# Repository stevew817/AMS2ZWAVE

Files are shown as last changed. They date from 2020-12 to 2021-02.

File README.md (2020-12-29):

# AMS2ZWAVE
Converter for Norwegian EMI HAN interface to Z-Wave

# Disclaimer
This is a hobby project, and as such will be supported if and when I have the time.

The project is assumed to work for my situation, but it might not work for you. Use at your own risk.

Furthermore, since I am not a member of the Z-Wave SDO, there is no manufacturer/product ID officially assigned to this device.
I don't have the funds required to certify this device, nor the wish to do so myself. This means the IDs in use in this firmware can
be assigned to another manufacturer at any given point in time, breaking the operation of this device in hubs that utilize
device databases (which would be all of them given device configuration parameters are not always discoverable on the network).

Or, more likely, there will be other hobby projects that choose to use the same ID as the default in here.
In that case, you'll have to recompile one of them yourself with a different ID to avoid collisions if they're to be used against the same hub.

If you are affiliated with an SDO-registered company and wish to take this design to market, feel free to do so. I'd appreciate a heads-up, though.

# License
Hardware design is licensed CC-BY: https://creativecommons.org/licenses/by/4.0/

The Z-Wave application code is adapted from a sample application [supplied by Silicon Labs on Github](https://github.com/SiliconLabs/z_wave_applications/tree/1341a074053843d77aac94dc1ba609a796c5856e/z_wave_gesture_sensor_wall_controller_application). The sample applications in that repository are licensed under the Zlib license, and so are my modifications.

Other files that do not originate from the sample application (notably my own HAN parser), are also licensed under the Zlib license.

# Hardware
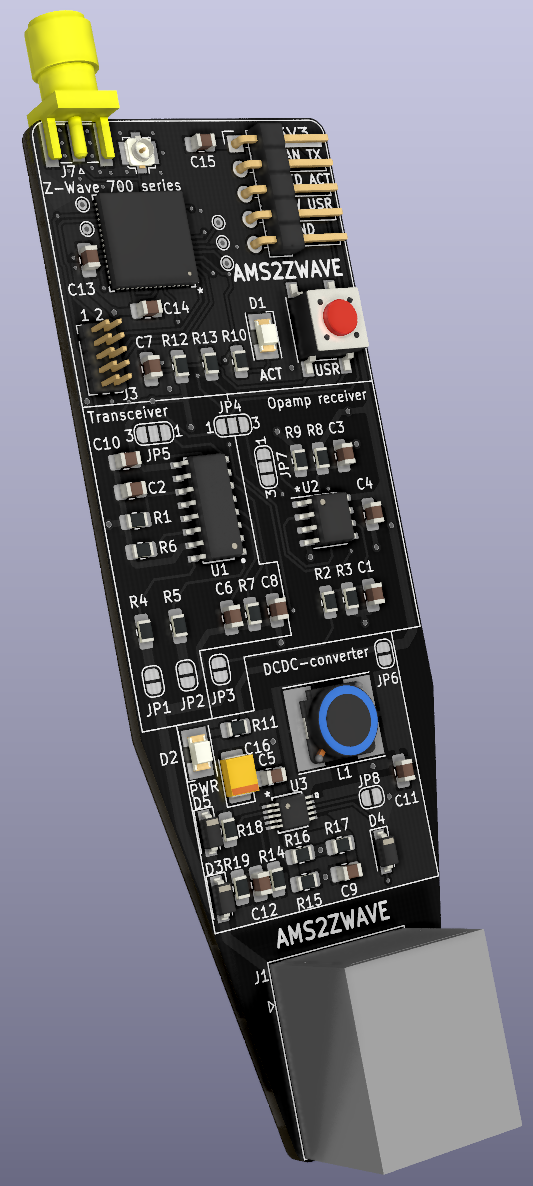
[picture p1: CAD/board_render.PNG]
Prototype hardware design Prototype PCB render


[PDF Schematic](CAD/AMS2ZWAVE.pdf)

Schematic and board layout are done in KiCAD, and source files can be found in the `CAD` folder.
[Production files for my prototype order](CAD/Gerber/ams2zwave_v1.zip) are also supplied.

## Choice of Z-Wave circuit
I consider this design to be hand-solderable, with the exception of the ZGM130S System-in-Package. Until a Z-Wave 700 series module is
designed and brought to market with a more hobbyist-friendly form factor, you'll have to use a stencil and solder paste to reflow that part.

For prototyping purposes, this design also contains a header to allow it to be wired up to a development kit, instead of having to solder down the ZGM130S.
In that case, the design will act as a bus level translator, power supply and user interface.
For a Silicon Labs WSTK (BRD4001) with ZGM130S plug-in card (BRD4202), wire the `J4` header as follows to the WSTK's `EXP` header:

| Signal | J4  | EXP | ZGM130S |
| --- | --- | --- | --- |
| VMCU | 1 | 2 | (A)VDD(IO) |
| GND | 5 | 1 | GND |
| HAN_TX | 2 | 6 | PC7 / USART1_RX |
| LED1 | 3 | 13  | PF3 |
| BTN1 | 4 | 9 | PF7 |

## Choice of bus level translation
Norwegian HAN is M-Bus with a twist: all meters observed to date supply 24V 'at rest' (space).
[Mark signal should be 12V under the space voltage](https://m-bus.com/documentation-wired/04-physical-layer), so with that in mind, I have prototyped
two different circuits for converting the HAN signal level to 3V3 TTL.

### Dedicated IC
The 'transceiver' circuit uses an m-bus transceiver, but foregoes using its internal LDO for powering the Z-Wave circuit in favor of a separate DCDC. Avoiding
using the LDO allows the circuit to be much more efficient and not trip any overcurrent protections in the HAN bus master implementation.

Using a transceiver is a more expensive solution, but should also be more reliable in case another meter appears that decides to use actual M-bus voltages (+36/+24)
instead of the currently observed de-facto +24/+12 signal.

Pin-compatible devices are TI's TSS521/TSS721 or ON Semi's NCN5150.

### Opamp
A cheaper alternative (but needs to be validated that it works) is a comparator circuit driven off of the 3V3 supply, looking at the HAN signal through a simple
voltage divider. The resistor values specified would divide the input signal by 12 (i.e. 2V space, 1V mark) and put the reference voltage at 1.75V.

### Setting the jumpers

| Jumper | Function | Default setting (uncut/unsoldered) |
| --- | --- | --- |
| JP6 | Connect DCDC output to 3V3 line | connected |
| JP1 | Connect HAN port input 1 to transceiver circuit | unconnected |
| JP2 | Connect HAN port input 2 to transceiver circuit | unconnected |
| JP3 | Connect HAN port input to opamp circuit | unconnected |
| JP5 | Select between normal (1) or inverted (3) transceiver output | normal |
| JP7 | Select between normal (1) or inverted (3) opamp output | normal |
| JP4 | Select source of `HAN_TX` signal between transceiver (1)(output of `JP5`) and opamp (3)(output of `JP7`) circuit  | transceiver / JP5 |

Of note: this circuit won't give you any signal by default. You need to choose to either use the transceiver-based circuit for level translation by soldering
jumpers `JP1` and `JP2`, or select the opamp circuit by soldering `JP3` and moving `JP4` from its default 1-2 position to 2-3.

## DCDC converter and power consumption
The DCDC converter is based around a MAX17531 step-down converter, and designed according to [the datasheet's figure 7](https://datasheets.maximintegrated.com/en/ds/MAX17531.pdf),
*High-Efficiency 3.3V, 50mA Regulator*. Under normal operation, the device will draw about 10 - 14 mA from the 3V3 line, meaning it will be operating at
about 85% efficiency.

This results in a top power draw of about 50mW from the HAN interface (plus the transceiver circuit's static current draw), which is well within spec
for all of the currently deployed meters in Norway. The lowest-power ones (Kamstrup meters) are spec'ed to supply 144mW / 6mA continuously.

## Z-Wave circuit
The circuit was designed based off of the Silicon Labs reference design boards (BRD4202A and BRD8901A, available in Simplicity Studio). Due to the nature
of the SiP, the core design is *extremely* lightweight: 2 decouple caps and an antenna connector. The distance between the SiP and the connector is so short
vs. the wavelength, that impedance control is unlikely to make a difference. The SiP's output is already matched to 50 ohm, so as long as the connected antenna
is also matched to 50 ohms, the design should be good to go.

Debug connector is a 0.05" pitch, 2x5 pinheader. The pinout matches the 'mini simplicity' connector described in Silicon Labs' [application note AN958](https://www.silabs.com/documents/public/application-notes/an958-mcu-stk-wstk-guide.pdf).
This makes it so that the circuit can be debugged by a Silicon Labs development kit [with the appropriate adapter](https://www.silabs.com/development-tools/mcu/32-bit/simplicity-debug-adapter), or
really any other SWD debug probe with the 10-pin ARM connector. Using the Silicon Labs kit gives the possibility to trace energy usage and have a debug serial port
from inside the IDE, though.

The button and activity LED are routed to the same pins as in the Z-Wave SDK's reference applications.

The HAN signal is routed to the Z-Wave SDK's reference application 'USART 1' RX pin. It's a 2400 baud 8-N-1 or 8-E-1 signal.

# Software
The software is an adaptation of the ['Gesture Wall Controller' Z-Wave sample app](https://github.com/SiliconLabs/z_wave_applications/tree/master/z_wave_gesture_sensor_wall_controller_application).

Changes include:
* Stripped out 'central scene' CC and dependencies
* Stripped out associations that are not the lifeline group
* Implemented 'meter' CC
* Changed device type to 'generic meter'
* Bogus manufacturer/product ID
* Implemented a parser for the HAN signal:
    * Uses list identifiers to parse the incoming information. This means a firmware update would be required to support any new meters appearing on the Norwegian market. Shouldn't be much of an issue, since the firmware does support OTA updates.
    * Lives in a [separate repository](http://github.com/stevew817/ams-han-parser)
* Implemented configuration CC to support changing the reporting frequency
    * The Configuration CC should be easily usable by other projects as well, as it was written generically.

Todo:
* Add separate endpoints for getting phase-specific values on three-phase meters (root endpoint currently reports L1 values for voltage and current).
* Add support for reporting both active and reactive power / energy
* Add support for reporting export direction

To build the firmware:
1. Download and install Simplicity Studio
2. Install the Z-Wave SDK inside Simplicity Studio (project was created with Z-Wave SDK 7.15.x)
3. Import this repository (including submodules) as a project into Simplicity Studio
4. Build

To fully flash a blank device:
1. Flash the bootloader (`bin/AMS2ZWAVE-btl-combined.s37`) to the device
    * This is the same bootloader as the SDK-provided one, except it allows firmware downgrading and sidegrading.
2. Flash the sign & encrypt keys to the device, following [step 7 in this guide](https://www.silabs.com/community/wireless/z-wave/knowledge-base.entry.html/2019/04/09/z-wave_700_ota_ofe-i00M)
    * This repository is set up to generate .gbl files using the 'default' keys in the SDK, so you don't have to generate your own
    * For the default keys, flash these files using commander with the --tokenfile argument:
        * `${StudioSdkPath}/protocol/z-wave/BootLoader/sample-keys/sample_encrypt.key`
        * `${StudioSdkPath}/protocol/z-wave/BootLoader/sample-keys/sample_sign.key-tokens.txt`
3. Flash the application like you normally would
4. Verify debug output to check the device is working and responsive

## Z-Wave operation
Device only has a single association group, which is the lifeline group. It will report meter updates unsolicited to the node registered to the lifeline group.
Frequent updates report power draw, whilst the accumulated meter reading is only reported once an hour (see the HAN standard from NEK). This is a limitation of the HAN standard.

The node could theoretically average the reported power draw in-between getting the accumulated meter reading reports, but since some meters only report power for the last second every 10s, that opens up a possibility of averaging higher than actual, and thus 'overestimating' the meter reading within the hour. That would mean the reported accumulated value could potentially go backwards once an hour, and it's not a given that various systems will be able to cope with that.

The controller can ask ('poll') for other values (like voltage and current), but there is currently no support for reporting these automatically.
I consider the use case for grabbing these values fairly narrow, since line voltage shouldn't deviate from 230V too much, and you can calculate backwards from
the reported power draw to get a 'good-enough' estimation of current.

## Development
The root of this repository is importable as a Simplicity Studio project, and targets the Z-Wave SDK version 7.15.4. Both Simplicity Studio and the Z-Wave SDK
are free downloads after registering with Silicon Labs.

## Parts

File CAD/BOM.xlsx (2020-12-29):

 |  |  |  |  |  | prototype build |  | transceiver build |  | opamp build
category | Description | symbol | footprint | part number | unit price | count | total price | count | total price | count | total price | proto stock | Mouser bom
mechanical | SubGHz antenna |  |  | ANTX150P116B08683 | 1.5 | 1 | 1.5 | 1 | 1.5 | 1 | 1.5 |  | X
 | PCB |  |  |  | 1 | 1 | 1 | 1 | 1 | 1 | 1
 | RJ45 connector | J1 | amphenol 54602-x08 | 54602-908LF | 0.5 | 1 | 0.5 | 1 | 0.5 | 1 | 0.5 |  | X
DCDC | DCDC converter | U3 | 10-MSOP | MAX17531AUB | 1.5 | 1 | 1.5 | 1 | 1.5 | 1 | 1.5 |  | X
 | Low-Vf schottky diode, 30V | D3 | SOD-123 | BAT54GWX | 0.1 | 1 | 0.1 | 1 | 0.1 | 1 | 0.1 |  | X
 | Input capacitor, 30V 1uF | C5 | 0805 | CL21B105KBFNNNE | 0.05 | 1 | 0.05 | 1 | 0.05 | 1 | 0.05 |  | X
 | Output capacitor, 5V 10uF low ESR | C11 | 0805 | CL21A106KQFNNNG | 0.07 | 1 | 0.07 | 1 | 0.07 | 1 | 0.07 | X | X
 | reference stabilisation cap, 5V 220nF | C9 | 0805 | CL21B224KBFNNNG | 0.05 | 1 | 0.05 | 1 | 0.05 | 1 | 0.05 |  | X
 | Precision resistor 49.9k | R15 | 0805 | RC0805FR-0749K9L | 0.02 | 1 | 0.02 | 1 | 0.02 | 1 | 0.02 |  | X
 | Precision resistor 158k | R16 | 0805 | RC0805FR-07158KL | 0.02 | 1 | 0.02 | 1 | 0.02 | 1 | 0.02 |  | X
 | Precision resistor 140k | R14 | 0805 | RC0805FR-07140KL | 0.02 | 1 | 0.02 | 1 | 0.02 | 1 | 0.02 |  | X
 | Precision resistor 22.1 Ohm | R17 | 0805 | RC0805FR-0722R1L | 0.02 | 1 | 0.02 | 1 | 0.02 | 1 | 0.02 |  | X
 | Low-impedance inductor 220uH | L1 | 8040 | TYS8040221M-10 | 0.3 | 1 | 0.3 | 1 | 0.3 | 1 | 0.3 |  | X
 | Low-Vf schottky diode, 5V | D4 | SOD-123 | BAT54GWX | 0.1 | 1 | 0.1 | 1 | 0.1 | 1 | 0.1 |  | X
Transceiver | mbus transceiver | U1 | SOIC-16 | NCN5150DR2G | 2 | 1 | 2 | 1 | 2 |  |  |  | X
 | Bus termination resistor, 220 Ohm | R4, R5 | 0805 | RC0805FR-0722RL | 0.02 | 2 | 0.04 | 2 | 0.04 |  |  |  | X
 | Bus current set resistor, 470Ohm | R6 | 0805 | RC0805FR-07470RL | 0.02 | 1 | 0.02 | 1 | 0.02 |  |  |  | X
 | Slave current resistor, 82k | R7 | 0805 | RC0805FR-0782KL | 0.02 | 1 | 0.02 | 1 | 0.02 |  |  |  | X
 | transceiver decouple resistor, 100k | R1 | 0805 | RC0805FR-07100KL | 0.02 | 1 | 0.02 | 1 | 0.02 |  |  | X | X
 | Transceiver decouple cap, 100n | C2 | 0805 | CL21B104KCFNNNE | 0.02 | 1 | 0.02 | 1 | 0.02 |  |  | X | X
 | IO decouple cap, 100n | C10 | 0805 | CL21B104KCFNNNE | 0.02 | 1 | 0.02 | 1 | 0.02 |  |  | X | X
 | Bus level storage cap, 100n | C8 | 0805 | CL21B104KCFNNNE | 0.02 | 1 | 0.02 | 1 | 0.02 |  |  | X | X
 | Supply backup cap, 1u | C6 | 0805 | CL21B105KOFNNNG | 0.05 | 1 | 0.05 | 1 | 0.05 |  |  | X | X
Opamp | opamp | U2 | SOIC-8 | LM358LVIDR | 0.3 | 1 | 0.3 |  |  | 1 | 0.3 |  | X
 | decouple cap 100n | C4 | 0805 | CL21B104KCFNNNE | 0.02 | 1 | 0.02 |  |  | 1 | 0.02 | X | X
 | Voltage divider resistor 33k (11/12) | R2 | 0805 | RC0805FR-0733KL | 0.02 | 1 | 0.02 |  |  | 1 | 0.02 |  | X
 | Voltage divider resistor 3k (1/12) | R3 | 0805 | RC0805FR-073KL | 0.02 | 1 | 0.02 |  |  | 1 | 0.02 |  | X
 | Voltage divider resistor 24k (47%) | R8 | 0805 | RC0805FR-0724KL | 0.02 | 1 | 0.02 |  |  | 1 | 0.02 |  | X
 | Voltage divider resistor 27k (53%) | R9 | 0805 | RC0805FR-0727KL | 0.02 | 1 | 0.02 |  |  | 1 | 0.02 |  | X
 | Divider stabilising caps 100n | C1, C3 | 0805 | CL21B104KCFNNNE | 0.02 | 2 | 0.04 |  |  | 2 | 0.04 | X | X
Z-Wave | ZGM130S | U4 | LGA64 | ZGM130S037HGN2R | 6 | 1 | 6 | 1 | 6 | 1 | 6 |  | X
 | ZGM decoupling caps 10uF | C13, C14 | 0805 | CL21A106KQFNNNG | 0.07 | 2 | 0.14 | 2 | 0.14 | 2 | 0.14 | X | X
 | U.fl / ipex connector | J2 | U.fl | Molex 73412-0110 | 0.6 | 1 | 0.6 | 1 | 0.6 | 1 | 0.6 |  | X
 | Mini simplicity connector | J3 | .05" 2x5 male header | 20021111-00010T1LF | 0.5 | 1 | 0.5 | 0 | 0 | 0 | 0 |  | X
 | Prototype connector | J4 | right-angle .1" pinhd | 10129379-905001BLF | 0.08 | 1 | 0.08 | 0 | 0 | 0 | 0 | X | X
 | Input decouple prototype 100n | C15 | 0805 | CL21B104KCFNNNE | 0.02 | 1 | 0.02 | 0 | 0 | 0 | 0 | X | X
 | LED current limiting resistors 3k | R10, R11 | 0805 | RC0805FR-073KL | 0.02 | 2 | 0.04 | 2 | 0.04 | 2 | 0.04 |  | X
 | Power-on indicator LED, red | D1 | PLCC2 | CLM3C-RKW-CUBVAAA3 | 0.15 | 1 | 0.15 | 1 | 0.15 | 1 | 0.15 |  | X
 | Zwave activity LED, amber | D2 | PLCC2 | CLM3C-AKW-CUAVB253 | 0.15 | 1 | 0.15 | 1 | 0.15 | 1 | 0.15 |  | X
 | Zwave user button | SW1 | 6x6mm | PTS645SK50SMTR92LFS | 0.14 | 1 | 0.14 | 1 | 0.14 | 1 | 0.14 |  | X
 | User button pullup 1M | R12 | 0805 | RC0805FR-071ML | 0.04 | 1 | 0.04 | 1 | 0.04 | 1 | 0.04 |  | X
 | User button snubber cap 1n | C7 | 0805 | CL21B102KBANNNC | 0.04 | 1 | 0.04 | 1 | 0.04 | 1 | 0.04 |  | X
 | User button snubber r, 100 Ohm | R13 | 0805 | RC0805FR-07100RL | 0.02 | 1 | 0.02 | 1 | 0.02 | 1 | 0.02 | X | X
 |  |  |  |  | USD |  | 15.82 |  | 14.78 |  | 13.01

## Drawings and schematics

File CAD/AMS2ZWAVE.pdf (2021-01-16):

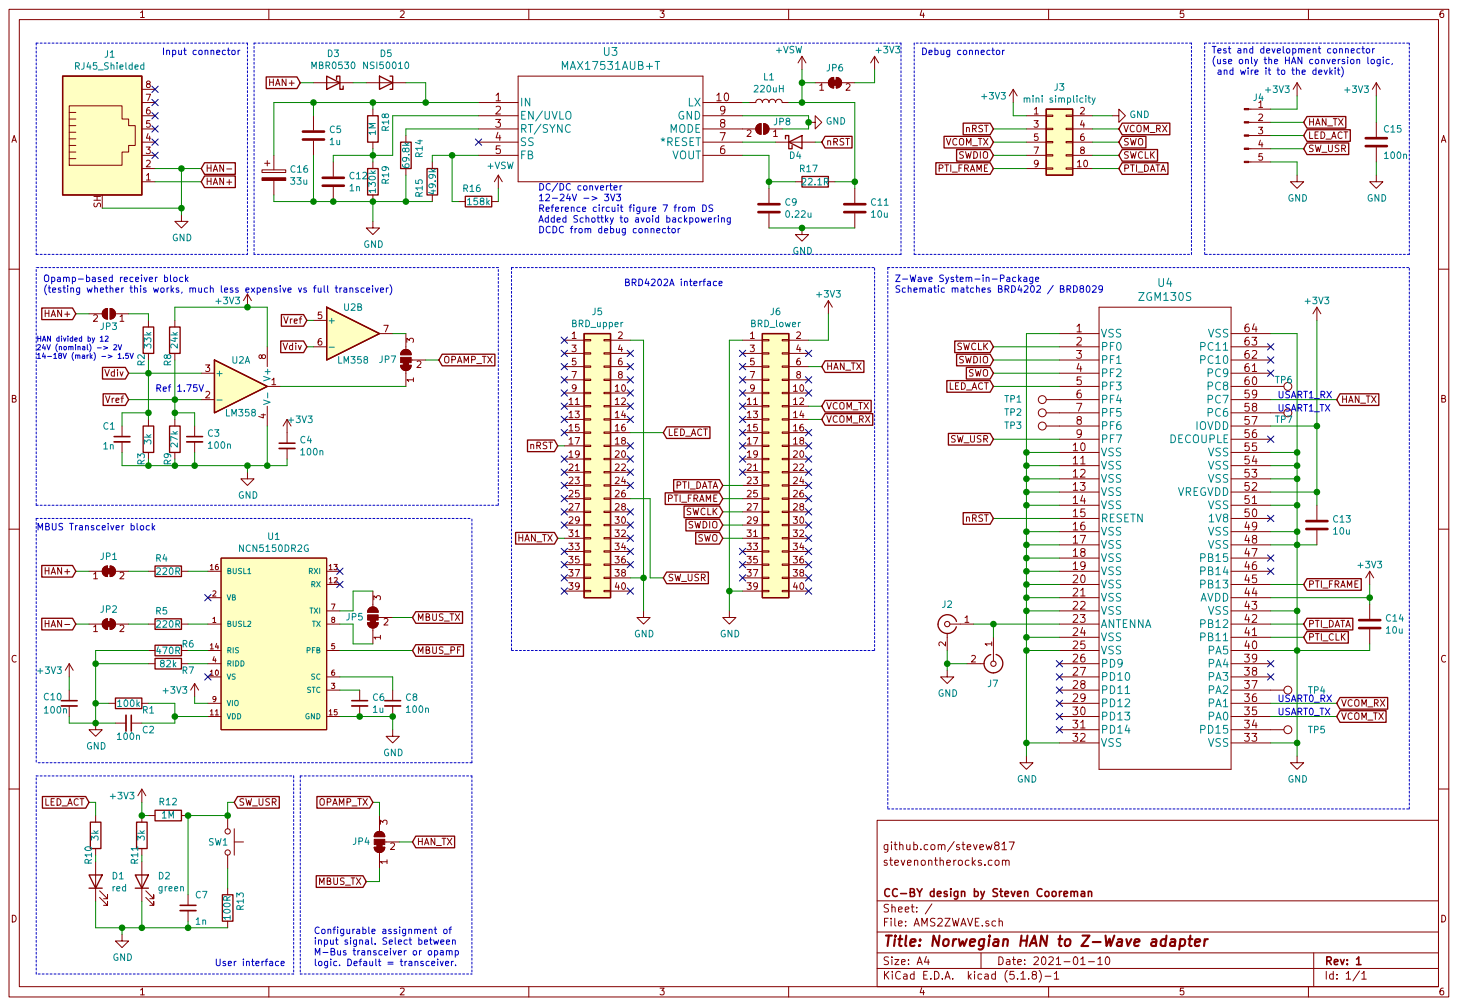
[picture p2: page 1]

(use only the HAN conversion logic,

Added Schottky to avoid backpowering
DCDC from debug connector
100n GND

14-18V (mark) -> 1.5V Opamp-based receiver block

Id: 1/1 Title: Norwegian HAN to Z-Wave adapter File: AMS2ZWAVE.sch Sheet: / CC-BY design by Steven Cooreman

input signal. Select between

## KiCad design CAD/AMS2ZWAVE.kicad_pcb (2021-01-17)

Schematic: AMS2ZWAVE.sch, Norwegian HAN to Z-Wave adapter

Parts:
C1, C7, C12: 1n; C_0805_2012Metric_Pad1.18x1.45mm_HandSolder
C2, C3, C4, C8, C10, C15: 100n; C_0805_2012Metric_Pad1.18x1.45mm_HandSolder
C5, C6: 1u; C_0805_2012Metric_Pad1.18x1.45mm_HandSolder
C9: 0.22u; C_0805_2012Metric_Pad1.18x1.45mm_HandSolder
C11, C13, C14: 10u; C_0805_2012Metric_Pad1.18x1.45mm_HandSolder
C16: 33u; CP_EIA-2012-12_Kemet-R_Pad1.30x1.05mm_HandSolder
D1: red; LED_PLCC-2
D2: green; LED_PLCC-2
D3, D4: MBR0530; D_SOD-123
D5: NSI50010; D_SOD-123
J1: RJ45_Shielded; RJ45_Amphenol_54602-x08_Horizontal
J2: Conn_Coaxial; U.FL_Molex_MCRF_73412-0110_Vertical
J3: mini simplicity; PinHeader_2x05_P1.27mm_Vertical
J4: Conn_01x05_Male; PinHeader_1x05_P2.54mm_Horizontal
J5: BRD_upper; PinHeader_2x20_P1.27mm_Vertical_SMD
J6: BRD_lower; PinHeader_2x20_P1.27mm_Vertical_SMD
J7: Conn_Coaxial; SMA_Samtec_SMA-J-P-X-ST-EM1_EdgeMount
JP1, JP2: SolderJumper_2_Open; SolderJumper-2_P1.3mm_Bridged_RoundedPad1.0x1.5mm
JP3, JP8: SolderJumper_2_Open; SolderJumper-2_P1.3mm_Open_RoundedPad1.0x1.5mm
JP4, JP5, JP7: SolderJumper_3_Bridged12; SolderJumper-3_P1.3mm_Bridged12_RoundedPad1.0x1.5mm_NumberL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
JP6: SolderJumper_2_Bridged; SolderJumper-2_P1.3mm_Bridged2Bar_RoundedPad1.0x1.5mm
L1: 220uH; L_Taiyo-Yuden_NR-80xx_HandSoldering
R1: 100k; R_0805_2012Metric_Pad1.20x1.40mm_HandSolder
R2: 33k; R_0805_2012Metric_Pad1.20x1.40mm_HandSolder
R3, R10, R11: 3k; R_0805_2012Metric_Pad1.20x1.40mm_HandSolder
R4, R5: 220R; R_0805_2012Metric_Pad1.20x1.40mm_HandSolder
R6: 470R; R_0805_2012Metric_Pad1.20x1.40mm_HandSolder
R7: 82k; R_0805_2012Metric_Pad1.20x1.40mm_HandSolder
R8: 24k; R_0805_2012Metric_Pad1.20x1.40mm_HandSolder
R9: 27k; R_0805_2012Metric_Pad1.20x1.40mm_HandSolder
R12, R18: 1M; R_0805_2012Metric_Pad1.20x1.40mm_HandSolder
R13: 100R; R_0805_2012Metric_Pad1.20x1.40mm_HandSolder
R14: 69.8k; R_0805_2012Metric_Pad1.20x1.40mm_HandSolder
R15: 49.9k; R_0805_2012Metric_Pad1.20x1.40mm_HandSolder
R16: 158k; R_0805_2012Metric_Pad1.20x1.40mm_HandSolder
R17: 22.1R; R_0805_2012Metric_Pad1.20x1.40mm_HandSolder
R19: 130k; R_0805_2012Metric_Pad1.20x1.40mm_HandSolder
SW1: SW_Push; SW_SPST_PTS645
TP1, TP2, TP3, TP4, TP5, TP6, TP7: TestPoint; TestPoint_THTPad_D1.0mm_Drill0.5mm
U1: NCN5150DR2G; On_Semiconductor-NCN5150DR2G
U2: LM358; SOIC-8_3.9x4.9mm_P1.27mm
U3: MAX17531AUB+T; MAX17531AUB&plus_T
U4: ZGM130S

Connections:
+3V3: C4.1, C10.1, C13.1, C14.1, C15.1, J3.1, J4.1, J6.2, JP6.2 (B), R8.2, R11.2, R12.1, U1.9 (VIO), U2.8 (V+), U4.44 (AVDD), U4.52 (VREGVDD), U4.57 (IOVDD)
+VSW: C11.1, JP6.1 (A), L1.2, R16.1, R17.1
HAN+: D3.2 (A), J1.1, JP1.1 (A), JP3.2 (B)
HAN-: C1.2, C2.2, C3.2, C4.2, C5.2, C6.2, C7.2, C8.2, C9.2, C10.2, C11.2, C12.2, C13.2, C14.2, C15.2, C16.2, D1.1 (K), D2.1 (K), J1.2, J1.SH, J2.2 (Ext), J3.2, J4.5, J5.2, J5.38, J6.1, J6.39, J7.2 (Ext), JP2.1 (A), JP8.1 (A), R1.2, R3.1, R6.2, R7.2, R9.1, R13.1, R14.2, R15.2, R19.1, U1.15 (GND), U2.4 (V-), U3.9 (GND), U4.1 (VSS), U4.10 (VSS), U4.11 (VSS), U4.12 (VSS), U4.13 (VSS), U4.14 (VSS), U4.16 (VSS), U4.17 (VSS), U4.18 (VSS), U4.19 (VSS), U4.20 (VSS), U4.21 (VSS), U4.22 (VSS), U4.24 (VSS), U4.25 (VSS), U4.32 (VSS), U4.33 (VSS), U4.40 (PA5), U4.43 (VSS), U4.48 (VSS), U4.49 (VSS), U4.51 (VSS), U4.53 (VSS), U4.54 (VSS), U4.55 (VSS), U4.64 (VSS)
HAN_TX: J4.2, J5.31, J6.6, JP4.2 (C), U4.59 (PC7)
LED_ACT: J4.3, J5.16, R10.2, U4.5 (PF3)
MBUS_PF: U1.5 (PFB)
MBUS_TX: JP4.1 (A), JP5.2 (C)
unnamed: C2.1, R1.1, U1.11 (VDD)
unnamed: C6.1, U1.3 (STC)
unnamed: C8.1, U1.6 (SC)
unnamed: C9.1, R17.2, U3.6 (VOUT)
unnamed: C12.1, R18.1, R19.2, U3.2 (EN/UVLO)
unnamed: C5.1, C16.1, D5.1, R18.2, U3.1 (IN)
unnamed: D1.2 (A), R10.1
unnamed: D2.2 (A), R11.1
unnamed: D3.1 (K), D5.2
unnamed: D4.1 (K), U3.7 (*RESET)
unnamed: J2.1 (In), J7.1 (In), U4.23 (ANTENNA)
unnamed: JP1.2 (B), R4.2
unnamed: JP2.2 (B), R5.2
unnamed: JP3.1 (A), R2.2
unnamed: JP5.1 (A), U1.8 (TX)
unnamed: JP5.3 (B), U1.7 (TXI)
unnamed: JP7.1 (A), U2.1
unnamed: JP7.3 (B), U2.7
unnamed: JP8.2 (B), U3.8 (MODE)
unnamed: L1.1, U3.10 (LX)
unnamed: R4.1, U1.16 (BUSL1)
unnamed: R5.1, U1.1 (BUSL2)
unnamed: R6.1, U1.14 (RIS)
unnamed: R7.1, U1.4 (RIDD)
unnamed: R13.2, SW1.2
unnamed: R14.1, U3.3 (RT/SYNC)
unnamed: R15.1, R16.2, U3.5 (FB)
unnamed: TP1.1, U4.6 (PF4)
unnamed: TP2.1, U4.7 (PF5)
unnamed: TP3.1, U4.8 (PF6)
unnamed: TP4.1, U4.37 (PA2)
unnamed: TP5.1, U4.34 (PD15)
unnamed: TP6.1, U4.60 (PC8)
unnamed: TP7.1, U4.58 (PC6)
OPAMP_TX: JP4.3 (B), JP7.2 (C)
PTI_CLK: U4.41 (PB11)
PTI_DATA: J3.10, J6.23, U4.42 (PB12)
PTI_FRAME: J3.9, J6.25, U4.45 (PB13)
SWCLK: J3.8, J6.27, U4.2 (PF0)
SWDIO: J3.7, J6.29, U4.3 (PF1)
SWO: J3.6, J6.31, U4.4 (PF2)
SW_USR: C7.1, J4.4, J5.26, R12.2, SW1.1, U4.9 (PF7)
VCOM_RX: J3.4, J6.14, U4.36 (PA1)
VCOM_TX: J3.5, J6.12, U4.35 (PA0)
Vdiv: C1.1, R2.1, R3.2, U2.3 (+), U2.6 (-)
Vref: C3.1, R8.1, R9.2, U2.2 (-), U2.5 (+)
nRST: D4.2 (A), J3.3, J5.17, U4.15 (RESETN)

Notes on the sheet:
MBUS Transceiver block
Input connector
Opamp-based receiver block (testing whether this works, much less expensive vs full transceiver)
HAN divided by 12 24V (nominal) -> 2V 14-18V (mark) -> 1.5V
Ref 1.75V
DC/DC converter 12-24V -> 3V3 Reference circuit figure 7 from DS Added Schottky to avoid backpowering DCDC from debug connector
Debug connector
Test and development connector (use only the HAN conversion logic, and wire it to the devkit)
Configurable assignment of input signal. Select between M-Bus transceiver or opamp logic. Default = transceiver.
User interface
Z-Wave System-in-Package Schematic matches BRD4202 / BRD8029
USART1_RX
USART1_TX
USART0_RX
USART0_TX
BRD4202A interface

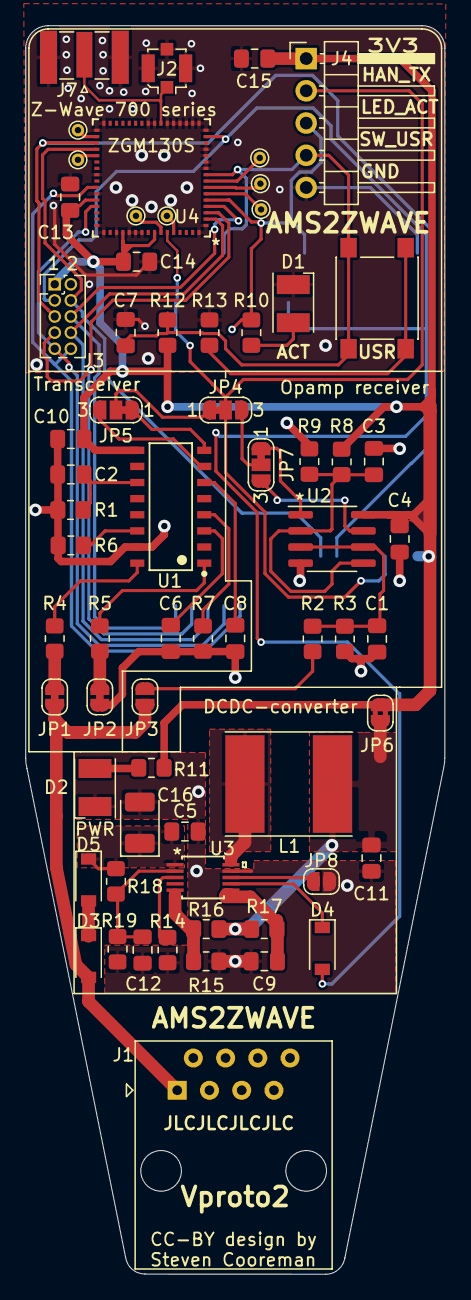
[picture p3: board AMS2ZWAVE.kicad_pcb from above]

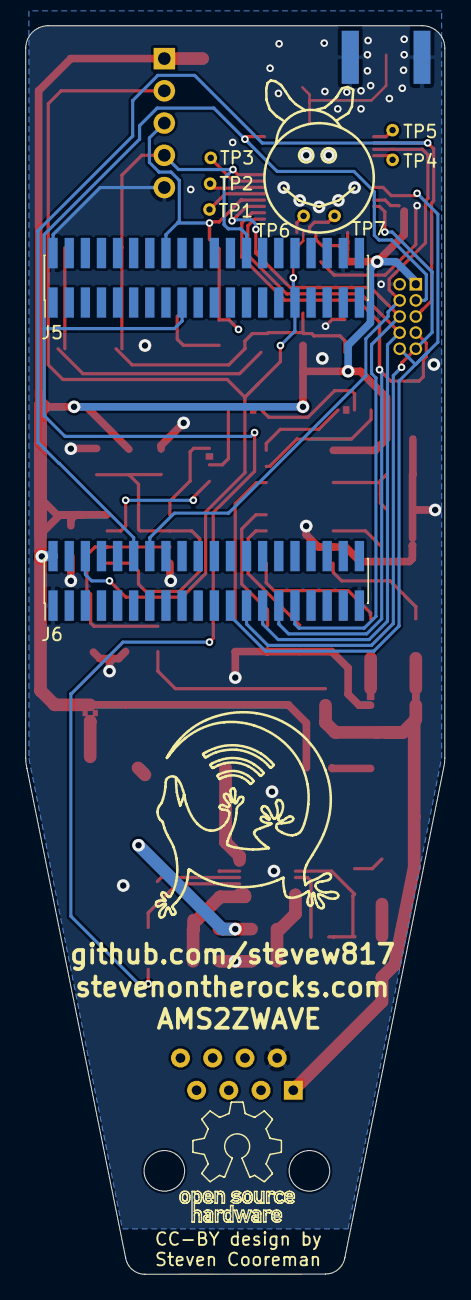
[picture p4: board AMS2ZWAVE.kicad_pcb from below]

Board: 2 copper layers, 33.0 x 98.4 mm, 68 parts (2 on the bottom side), 53 nets.

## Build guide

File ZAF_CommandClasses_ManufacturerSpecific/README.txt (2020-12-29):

Do not delete this folder, otherwise Simplicity Studio will delete the declared linked files from its project.

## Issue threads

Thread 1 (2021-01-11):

CC_CONFIGURATION_V4:   bulk_report_send()

N2641D, 2021-01-11:
Hi Steven,
This is an excellent project - congratulations!!! Also thank you for your answer about "CC_CONFIGURATION / CC_CONFIGURATION_V4" at the Z-Wave Wireless Forum.

I also have started to write a command class for CONFIGURATION two weeks ago and then recognized your work. When doing a few tests with the SiLabs ZWave Controller, I found that CONFIGURATION_BULK_GET_V4 and CONFIGURATION_BULK_SET_V4 (handshake=1) did not send any data back to the controller.

Having done a few changes (see // WP change) it now seems to work.

Best Regards,

Wilfried

-------------------------------------------

#include "SizeOf.h"                // WP change

// Start sending bulk report. Returns false if another bulk report is still in
// progress.
static bool bulk_report_send( uint16_t param, size_t num_param, bool handshake, TRANSMIT_OPTIONS_TYPE_SINGLE_EX *pTxOptionsEx) {
  // Figure out the size of the first parameter
  size_t param_size = 0;
  for( size_t i = 0; i < sizeof(parameter_table) / sizeof(parameter_table[0]); i++ ) {
    if( parameter_table[i].param_nbr == param ) {
      param_size = parameter_table[i].param_size;
      break;
    }
  }

  if( param_size == 0 ) {
      // parameter offset points to non-existing parameter
      // SDS13781 does not say what action we should take in this case,
      // except that 'The Configuration Bulk Report Command MUST be
      // returned in response to this command'. This implies we should
      // choose some arbitrary length and run with it?
      param_size = 1;
  }

  // For each parameter within the range, check whether they correspond to their
  // default.
  bool all_default = true;
  for( size_t i = 0; i < sizeof(parameter_table) / sizeof(parameter_table[0]); i++ ) {
    if( parameter_table[i].param_nbr >= param &&
        parameter_table[i].param_nbr < (param + num_param) ) {
      switch( param_size ) {
        case 1:
          if( *((uint8_t*)(parameter_table[i].param)) != parameter_table[i].param_default.u8 )
            all_default = false;
          break;
        case 2:
          if( *((uint16_t*)(parameter_table[i].param)) != parameter_table[i].param_default.u16 )
            all_default = false;
          break;
        case 4:
          if( *((uint32_t*)(parameter_table[i].param)) != parameter_table[i].param_default.u32)
            all_default = false;
          break;
        default:
          break;
      }
      break;
    }
  }

  uint8_t size_handshake_byte = (param_size & 0x7) | (handshake ? (1 << 6) : 0) | (all_default ? (1 << 7) : 0);
  size_t num_reports          = (num_param * param_size) / max_chars_per_report;
  if( (num_param * param_size) % max_chars_per_report != 0 ) num_reports++;

  if(handshake) {
    // Handshake response requires answering in a single packet
    num_reports = 1;
  }

  if(num_reports > 1) {
    // Need to start multipart report, check there's none in progress yet
    if( bulk_report_in_progress.in_progress ) return false;

    // Set up new multipart report
    bulk_report_in_progress.in_progress           = true;
    bulk_report_in_progress.pkg_options           = *pTxOptionsEx;
    bulk_report_in_progress.param_nbr             = param;
    bulk_report_in_progress.total_num_parameters  = num_param;
    bulk_report_in_progress.num_packets_remaining = num_reports;
    bulk_report_in_progress.size_handshake_byte   = size_handshake_byte;

    bulk_report_progress_cb( 0 );
  }
  else {
    // We can send this report at once
    ZAF_TRANSPORT_TX_BUFFER  TxBuf;
    ZW_APPLICATION_TX_BUFFER *pTxBuf = &(TxBuf.appTxBuf);
    memset((uint8_t*)pTxBuf, 0, sizeof(ZW_APPLICATION_TX_BUFFER) );

    // Name and info reports look identical besides their command ID.
    pTxBuf->ZW_ConfigurationBulkReport1byteV4Frame.cmdClass           = COMMAND_CLASS_CONFIGURATION_V4;
    pTxBuf->ZW_ConfigurationBulkReport1byteV4Frame.cmd                = CONFIGURATION_BULK_REPORT_V4;
    pTxBuf->ZW_ConfigurationBulkReport1byteV4Frame.parameterOffset1   = (param>>8) & 0xFF;  // WP change
    pTxBuf->ZW_ConfigurationBulkReport1byteV4Frame.parameterOffset2   = param & 0xFF;       // WP change
    pTxBuf->ZW_ConfigurationBulkReport1byteV4Frame.numberOfParameters = num_param;          // WP change
    pTxBuf->ZW_ConfigurationBulkReport1byteV4Frame.reportsToFollow    = 0;
    pTxBuf->ZW_ConfigurationBulkReport1byteV4Frame.properties1        = param_size;         // WP change

    uint8_t* param_buffer = (uint8_t*)&pTxBuf->ZW_ConfigurationBulkReport1byteV4Frame.variantgroup1;

    // Copy all parameters for this packet. It is assumed parameter existence and size
    // has been validated before ending up in this CB.
    for( size_t i = 0; i < num_param; i++ ) {
      // For each parameter number, find it in the table and copy its value
      bool param_found = false;
      for (size_t j=0; j<sizeof_array(parameter_table); j++) {                              // WP change
        if( parameter_table[j].param_nbr == param + i ) {                                   // WP change
          switch(param_size) {
            case 1:
              param_buffer[i * param_size] = *((uint8_t*)(parameter_table[j].param));
              break;
            case 2:
              param_buffer[i * param_size + 0] = *((uint16_t*)(parameter_table[j].param)) >> 8;
              param_buffer[i * param_size + 1] = *((uint16_t*)(parameter_table[j].param)) & 0xFF;
              break;
            case 4:
              param_buffer[i * param_size + 0] = (*((uint32_t*)(parameter_table[j].param)) >> 24) & 0xFF;
              param_buffer[i * param_size + 1] = (*((uint32_t*)(parameter_table[j].param)) >> 16) & 0xFF;
              param_buffer[i * param_size + 2] = (*((uint32_t*)(parameter_table[j].param)) >>  8) & 0xFF;
              param_buffer[i * param_size + 3] = (*((uint32_t*)(parameter_table[j].param)) >>  0) & 0xFF;
              break;
            default:
              break;
          }
          param_found = true;
          break;
        }
      }

      // SDS13781: A sending node SHOULD set this field to 0 for non-existing parameters
      if( !param_found ) memset(&param_buffer[i * param_size], 0, param_size);
    }
    size_t report_size = (num_param * param_size) + offsetof(ZW_CONFIGURATION_BULK_REPORT_1BYTE_V4_FRAME, variantgroup1);

    // Send it
    if( EQUEUENOTIFYING_STATUS_SUCCESS != Transport_SendResponseEP((uint8_t *)pTxBuf, report_size, pTxOptionsEx, NULL) ) {  // WP change
        ; // Job failed
    }
  }

  return true;
}

stevew817, 2021-01-11:
Thanks for the contribution, @N2641D! I'll try this tonight and pull it in.

stevew817, 2021-01-11:
@N2641D I've applied your feedback and fixed some more for the case where a report needs to be split across multiple messages. Can you check it out (should be on master branch now) on your end and give a thumbs up or down?

N2641D, 2021-01-12:
Hi Steven,

That was a really quick response. Thank you!

I have done a couple of tests and I think that there might be still some issues. I have created a test which contains 20 parameters 4bytes each. Their parameter offset is 1024…1043.

Unfortunately the SiLabs ZWave Controller’s log window has a bug to not wrap around the returned package data. I’m therefore unable to verify the returned package in detail (if the line gets too long).

Yesterday I forgot to highlight one change...

  // Copy all parameters for this packet. It is assumed parameter existence and size
  // has been validated before ending up in this CB.
  for( size_t i = 0; i < num_report_items; i++ ) {
    // For each parameter number, find it in the table and copy its value
    bool param_found = false;
    for( size_t j = 0; j < sizeof_array(parameter_table); j++ ) {
      if( parameter_table[j].param_nbr == this_pkt_param_start + i ) {
        param_found = true;

… which makes sure that the value will not be identified as “non existing parameter” and of course not be reset to 0. That line is missing for n packages too.

When increasing the numbers of parameters to be returned everything looks almost fine up to 9 parameters (e.g. 1 parameter: (70 09) + 04 00 01 00 84 00 00 01 00). One thing I’m not sure is whether or not the “Default” bit should be set (0x84)?

When increasing the number of parameters to 10 the CONFIGURATION_BULK_GET looks still okay (70 08 04 00 0A). Your code decides to still go with one package and everything looks okay, however, although the call:

    // Send it
    DPRINTF("**** SEND IT\r\n");
    if( EQUEUENOTIFYING_STATUS_SUCCESS != Transport_SendResponseEP((uint8_t *)pTxBuf, report_size, pTxOptionsEx, NULL) ) {
      DPRINTF("**** JOB FAILED ****\r\n");
        ; // Job failed
    }

is executed without error, no data will be sent! I therefore guess that 10x4byte values do exceed the maximum number of bytes per report and "max_chars_per_report = 40” must be decreased.
When increasing the BULK_GET request to 11 parameters, the returned package (04 0A 01 00 84 00 00 00 00) is no longer okay. The parameter offset 1024 showed "(04 0A)”.

In order to get the report right, please find enclosed my proposal for some changes of bulk_report_progress_cb() (lines changed: // WP change”).

As far as I could see (issue with log window) the returned reports seem to be okay. One last question… is the split between 1-block and n-blocks software required? I would think that n-blocks would also work for 1-block? … but I’m not an Z-Wave expert :-)

Have a great evening!

Best,

Wilfried

—————————————————————————————

static const size_t max_chars_per_report = 39;  // WP change

static void bulk_report_progress_cb( uint8_t status ) {
  ZAF_TRANSPORT_TX_BUFFER  TxBuf;
  ZW_APPLICATION_TX_BUFFER *pTxBuf = &(TxBuf.appTxBuf);
  memset((uint8_t*)pTxBuf, 0, sizeof(ZW_APPLICATION_TX_BUFFER));
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
stevew817, 2021-01-12:
Damn. Okay, I'll have a much closer look.

N2641D, 2021-01-12:
… I just did another quick test. I created 46 parameters (1 Byte each).  39 is the magic number we were looking for!

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

stevew817, 2021-01-12:
>  One last question… is the split between 1-block and n-blocks software required? I would think that n-blocks would also work for 1-block? … but I’m not an Z-Wave expert :-)

Yes, it should work. I made the distinction between single-packet and multi-packet response handling for two reasons:
1. When a multi-packet response is in progress to one node, we can still send single-packet responses to other nodes which might be querying us simultaneously
2. When the handshake bit is set, the response is expected to fit into a single packet, since the set command fit in a single packet as well. Since I was unsure about the sizing of the packet, splitting up the logic allowed me to 'override' the sizing calculations in case of replying to a bulk set command :)

There's definitely room for collapsing that into one given some more thought, but I'm not sure it would be a priority at this point. I'm assuming the compiler is smart enough to alias the common bits of code between two static functions in the same compilation unit :)

Should probably start reporting 'node busy' to the requesting node when a bulk get fails due to another one already being in flight, though.

> Unfortunately the SiLabs ZWave Controller’s log window has a bug to not wrap around the returned package data. I’m therefore unable to verify the returned package in detail (if the line gets too long).

Yeah, I ran into that too. Fortunately, it's just bad UI design: if your screen resolution is large enough (or even better, if you have two screens), you can 'drag' the right side of the window to be larger, and you'll see a mark appear for widening the message view visible column width. Took me some time before I noticed that.

> please find enclosed my proposal for some changes

Much appreciated! I pushed them through #3 onto master just now.

Closed 2021-01-12.

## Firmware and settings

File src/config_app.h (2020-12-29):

/**
 * @file config_rf.h
 *
 * Configuration file for AMS2ZWAVE.
 *
 * Adapted from the Silicon Labs Z-Wave sample application repository, which is
 * licensed under the Zlib license:
 *   https://github.com/SiliconLabs/z_wave_applications
 *
 * Modifications by Steven Cooreman, github.com/stevew817
 *******************************************************************************
 * Original license:
 *
 * copyright 2018 Silicon Laboratories Inc.
 *
 * SPDX-License-Identifier: Zlib
 *
 * The licensor of this software is Silicon Laboratories Inc.
 *
 * This software is provided 'as-is', without any express or implied
 * warranty. In no event will the authors be held liable for any damages
 * arising from the use of this software.
 *
 * Permission is granted to anyone to use this software for any purpose,
 * including commercial applications, and to alter it and redistribute it
 * freely, subject to the following restrictions:
 *
 * 1. The origin of this software must not be misrepresented; you must not
 *    claim that you wrote the original software. If you use this software
 *    in a product, an acknowledgment in the product documentation would be
 *    appreciated but is not required.
 * 2. Altered source versions must be plainly marked as such, and must not be
 *    misrepresented as being the original software.
 * 3. This notice may not be removed or altered from any source distribution.
 *
 *******************************************************************************/
#ifndef _CONFIG_APP_H_
#define _CONFIG_APP_H_

#include <ZW_product_id_enum.h>
#include <CC_ManufacturerSpecific.h>

/****************************************************************************
 *
 * Application version, which is generated during release of SDK.
 * The application developer can freely alter the version numbers
 * according to his needs.
 *
 ****************************************************************************/
#define APP_VERSION ZAF_VERSION_MAJOR
#define APP_REVISION ZAF_VERSION_MINOR
#define APP_PATCH ZAF_VERSION_PATCH

/****************************************************************************
 *
 * Defines device generic and specific types
 *
 ****************************************************************************/
//@ [GENERIC_TYPE_ID]
#define GENERIC_TYPE GENERIC_TYPE_METER
#define SPECIFIC_TYPE SPECIFIC_TYPE_NOT_USED
//@ [GENERIC_TYPE_ID]

/**
 * See ZW_basis_api.h for ApplicationNodeInformation field deviceOptionMask
 */
//@ [DEVICE_OPTIONS_MASK_ID]
#define DEVICE_OPTIONS_MASK   APPLICATION_NODEINFO_LISTENING
//@ [DEVICE_OPTIONS_MASK_ID]

/****************************************************************************
 *
 * Defines used to initialize the Z-Wave Plus Info Command Class.
 *
 ****************************************************************************/
//@ [APP_TYPE_ID]
#define APP_ROLE_TYPE ZWAVEPLUS_INFO_REPORT_ROLE_TYPE_SLAVE_ALWAYS_ON
#define APP_NODE_TYPE ZWAVEPLUS_INFO_REPORT_NODE_TYPE_ZWAVEPLUS_NODE
#define APP_ICON_TYPE ICON_TYPE_GENERIC_WHOLE_HOME_METER_SIMPLE
#define APP_USER_ICON_TYPE ICON_TYPE_GENERIC_WHOLE_HOME_METER_SIMPLE
//@ [APP_TYPE_ID]

/****************************************************************************
 *
 * Defines used to initialize the Manufacturer Specific Command Class.
 *
 ****************************************************************************/
//NOTE: These values are not actually assigned to this product. Should you
//      choose to run this firmware in your local Z-Wave network, you should
//      be aware that there will be no interoperability guarantees.
//      The AMS2ZWAVE code is not certified.
#define APP_MANUFACTURER_ID     MFG_ID_NOT_DEFINED
#define APP_PRODUCT_TYPE_ID     0xCA
#define APP_PRODUCT_ID          0xFE

#define APP_FIRMWARE_ID         APP_PRODUCT_ID | (APP_PRODUCT_TYPE_ID << 8)

/****************************************************************************
 *
 * Defines used to initialize the Association Group Information (AGI)
 * Command Class.
 *
 ****************************************************************************/
#define NUMBER_OF_ENDPOINTS         0
#define MAX_ASSOCIATION_GROUPS      1
#define MAX_ASSOCIATION_IN_GROUP    5

/*
 * File identifiers for application file system
 * Range: 0x00000 - 0x0FFFF
 */
#define FILE_ID_APPLICATIONDATA (0x00000)

//@ [AGI_TABLE_ID]
#define AGITABLE_LIFELINE_GROUP \
 {COMMAND_CLASS_DEVICE_RESET_LOCALLY, DEVICE_RESET_LOCALLY_NOTIFICATION}, \
 {COMMAND_CLASS_METER_V5, METER_REPORT_V5},\
 {COMMAND_CLASS_INDICATOR, INDICATOR_REPORT_V3}


#define  AGITABLE_ROOTDEVICE_GROUPS NULL
//@ [AGI_TABLE_ID]

/**
 * Security keys
 */
//@ [REQUESTED_SECURITY_KEYS_ID]
#define REQUESTED_SECURITY_KEYS (SECURITY_KEY_S0_BIT | SECURITY_KEY_S2_UNAUTHENTICATED_BIT | SECURITY_KEY_S2_AUTHENTICATED_BIT)
//@ [REQUESTED_SECURITY_KEYS_ID]
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

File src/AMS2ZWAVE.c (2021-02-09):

/**
 * @file AMS2ZWAVE.c
 * @brief Device reading electricity meter values from a Norwegian smart meter
 *        and reporting those through Z-Wave.
 *
 * Adapted from the Silicon Labs Z-Wave sample application repository, which is
 * licensed under the Zlib license:
 *   https://github.com/SiliconLabs/z_wave_applications
 *
 * Modifications by Steven Cooreman, github.com/stevew817
 *******************************************************************************
 * Original license:
 *
 * Copyright 2020 Silicon Laboratories Inc. www.silabs.com
 *
 * SPDX-License-Identifier: Zlib
 *
 * The licensor of this software is Silicon Laboratories Inc.
 *
 * This software is provided 'as-is', without any express or implied
 * warranty. In no event will the authors be held liable for any damages
 * arising from the use of this software.
 *
 * Permission is granted to anyone to use this software for any purpose,
 * including commercial applications, and to alter it and redistribute it
 * freely, subject to the following restrictions:
 *
 * 1. The origin of this software must not be misrepresented; you must not
 *    claim that you wrote the original software. If you use this software
 *    in a product, an acknowledgment in the product documentation would be
 *    appreciated but is not required.
 * 2. Altered source versions must be plainly marked as such, and must not be
 *    misrepresented as being the original software.
 * 3. This notice may not be removed or altered from any source distribution.
 *
 *******************************************************************************
 * # Experimental Quality
 * This code has not been formally tested and is provided as-is. It is not
 * suitable for production environments. In addition, this code will not be
 * maintained and there may be no bug maintenance planned for these resources.
 * Silicon Labs may update projects from time to time.
 ******************************************************************************/

/****************************************************************************/
/*                              INCLUDE FILES                               */
/****************************************************************************/
/* During development of your device, you may add features using command    */
/* classes which are not already included. Remember to include relevant     */
/* classes and utilities and add them in your make file.                    */
/****************************************************************************/

/**************************** Boilerplate includes ****************************/
#include "config_rf.h"
#include <stdbool.h>
#include <stdint.h>
#include "SizeOf.h"
#include "Assert.h"
#include "DebugPrintConfig.h"
#define DEBUGPRINT
#include "DebugPrint.h"
#include "config_app.h"
#include "ZAF_app_version.h"
#include <ZAF_file_ids.h>
#include "nvm3.h"
#include "ZAF_nvm3_app.h"
#include <em_system.h>
#include <ZW_radio_api.h>
#include <ZW_slave_api.h>
#include <ZW_classcmd.h>
#include <ZW_TransportLayer.h>

#include <ZAF_uart_utils.h>
#include <board.h>
#include <ev_man.h>

#include <AppTimer.h>
#include <SwTimer.h>
#include <EventDistributor.h>
#include <ZW_system_startup_api.h>
#include <ZW_application_transport_interface.h>

#include <association_plus.h>
#include <agi.h>

#include <CC_Association.h>
#include <CC_AssociationGroupInfo.h>
#include <CC_DeviceResetLocally.h>
#include <CC_Indicator.h>
#include <CC_ManufacturerSpecific.h>
#include <CC_MultiChanAssociation.h>
#include <CC_PowerLevel.h>
#include <CC_Security.h>
#include <CC_Supervision.h>
#include <CC_Version.h>
#include <CC_ZWavePlusInfo.h>
#include <CC_FirmwareUpdate.h>

#include <ZW_TransportMulticast.h>

#include <zaf_event_helper.h>
#include <zaf_job_helper.h>

#include <ZAF_Common_helper.h>
#include <ZAF_network_learn.h>
#include <ota_util.h>
#include <ZAF_TSE.h>
#include <ota_util.h>
#include <ZAF_CmdPublisher.h>
#include <em_wdog.h>
#include "events.h"

#include <ZAF_network_management.h>

/***************************** AMS2ZWAVE includes *****************************/
#include <string.h>
#include "hanparser.h"
#include "readings.h"
#include "em_usart.h"

#include "CC_Configuration.h"

/*********************** AMS2ZWAVE function prototypes ************************/
void HAN_callback(const han_parser_data_t* decoded_data);
void HAN_serial_rx();
void HAN_setup();
void HAN_loadFromNVM(void);
void HAN_storeToNVM(bool update_meter, bool update_accumulated);
void HAN_resetNVM(void);

void* CC_Meter_prepare_zaf_tse_data(RECEIVE_OPTIONS_TYPE_EX* pRxOpt);
void CC_Meter_update_power(void);
void CC_Meter_update_energy(void);
void CC_Meter_report_unhandled_as_voltage(
    TRANSMIT_OPTIONS_TYPE_SINGLE_EX txOptions,
    void* pData);
void CC_Meter_report_unhandled_as_current(
    TRANSMIT_OPTIONS_TYPE_SINGLE_EX txOptions,
    void* pData);


received_frame_status_t
handleCommandClassMeter(
  RECEIVE_OPTIONS_TYPE_EX *rxOpt,
  ZW_APPLICATION_TX_BUFFER *pCmd,
  uint8_t cmdLength);

received_frame_status_t
handleCommandClassConfiguration(
  RECEIVE_OPTIONS_TYPE_EX *rxOpt,
  ZW_APPLICATION_TX_BUFFER *pCmd,
  uint8_t cmdLength);
/******************* end AMS2ZWAVE function prototypes ************************/

/****************************************************************************/
/* Application specific button and LED definitions                          */
/****************************************************************************/

// AMS2ZWAVE does not have extra LEDs or buttons besides APP_BUTTON_LEARN_RESET
// and APP_LED_INDICATOR

static EZwaveCommandStatusType unhandledCommandStatus;
static EZwaveReceiveType unhandledPacket;

/****************************************************************************/
/*                      PRIVATE TYPES and DEFINITIONS                       */
/****************************************************************************/

/**
 * Application states. Function AppStateManager(..) includes the state
 * event machine.
 */
typedef enum _STATE_APP_
{
  STATE_APP_STARTUP,
  STATE_APP_IDLE,
  STATE_APP_LEARN_MODE,
  STATE_APP_RESET,
} STATE_APP;

/****************************************************************************/
/*                              PRIVATE DATA                                */
/****************************************************************************/
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

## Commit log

2020-12-29 Add schematic and PCB for prototype version
    [AMS2ZWAVE.kicad_pcb, AMS2ZWAVE.sch]
2020-12-29 Added BOM
    [BOM.xlsx]
2020-12-29 Add schematic in PDF
2020-12-29 Track last reported power
2020-12-29 Implement USART Rx in a better way
    Using task notification instead of event, and changing the buffer format, stopped the application from crashing.
    [AMS2ZWAVE.c]
2020-12-29 Move app data reset to own function
    [AMS2ZWAVE.c]
2020-12-29 Fix configuration CC info/name
    By moving consecutive packet sending into a callback function, we prevent
    exhausting the node's send queue.
    [AMS2ZWAVE.c]
2020-12-29 Added support for polling voltage and current on L1
    three-phase will have to wait for multi-endpoint support
2020-12-29 Store reset point to memory as it happens
    [AMS2ZWAVE.c]
2020-12-29 Minor updates
    * Added custom bootloader to the project for supporting OTA
    * Print DSK at boot for SmartStart
    * doc patch
2020-12-29 Fixed a bug causing smartstart to not work
    [AMS2ZWAVE.c]
2021-01-10 PCB iteration 2
    * Added inrush current limiter
    * Added footprint to use BRD4202 instead of soldering down ZGM130S
    [AMS2ZWAVE.kicad_pcb, AMS2ZWAVE.sch]
2021-01-15 Update to v2 PCB
    * Increased DCDC switching frequency to 600kHz
    * Added resistor divider for setting UVLO to 10V
    * Added solderjumper for DCDC mode
    * Added bulk capacitor to smooth out 12V swings on the input line
    [AMS2ZWAVE.kicad_pcb, AMS2ZWAVE.sch]
2021-01-16 Update to proto v2
    * Added edgemount SMA in addition to U.FL for antenna flexibility
    [AMS2ZWAVE.kicad_pcb, AMS2ZWAVE.sch]
2021-01-16 Update to proto v2
    * Added test points for LGA pads bordering on in-use pads, to avoid them from coming loose when too much heat is applied
    * Moved SMA edge connector around, it makes more sense to have it at the top
    * Tidied layout
    [AMS2ZWAVE.kicad_pcb, AMS2ZWAVE.sch]
2021-01-17 Added missing 3D models for SMA and RJ45 connectors
    [AMS2ZWAVE.kicad_pcb]
2021-01-26 It's minus 10 degrees outside and I don't want to freeze
    Postponing debugging to a warmer season. This workaround is good
    enough, and nobody is ever likely to notice.
    [AMS2ZWAVE.c]
2021-01-26 It's *still* extremely cold outside and resetting every 2-3h wasn't enough
    [AMS2ZWAVE.c]
2021-02-02 Temporarily piggyback off of voltage and current for debugging
    Hopefully I can figure out why it was halting without having to
    stand outside in the cold for hours with a debugger.
2021-02-09 Set UART priorities lower than the radio's
    Could potentially solve the hanging mystery?

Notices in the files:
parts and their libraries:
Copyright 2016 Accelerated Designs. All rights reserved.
